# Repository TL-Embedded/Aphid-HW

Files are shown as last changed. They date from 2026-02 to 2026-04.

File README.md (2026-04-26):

# Aphid-HW

The Aphid Debugger provides a SWD and UART link via FT2232.

The 10 pin connector is compatible with the [10 pin standard here](https://github.com/TL-Embedded/SWD-UART-CTX-10).

The DTR signal can be used to apply +5V to the target `VCC AUX`.
The RTS signal can be used to ground the target `Detect`.

| Pin | Signal | IO | Description |
| --- | --- | --- | --- |
| 1 | VCC Target | Power input | Reference voltage for logic IO |
| 2 | SWDIO | Logic bidirectional | SWD Data line |
| 3 | GND | | Common ground |
| 4 | SWCLK | Logic output | SWD Clock line |
| 5 | VCC Aux | Power output | 5V power output |
| 6 | N/C | | Not connected |
| 7 | TX | Logic output | UART Transmit |
| 8 | Detect | Open drain | Debugger presence indicator |
| 9 | RX | Logic input | UART Receive |
| 10  | Reset | Open drain | Reset signal |

> [!CAUTION]
> DTR is usually automatically enabled by most terminal programs, which will enable `VCC Aux`. Ensure your target supports +5V on this pin, or remove R11 to disable this output.

# SWD interface

The SWD Debug interface is available on port 0 of the FT2232 as a D2XX device. It provides control of the SWD interface & Reset.

This is intended to be compatible with [OpenOCD](https://openocd.org/) using the [aphid-v1.cfg](./config/aphid-v1.cfg) config.

This may be copied into your openocd scripts folder, ie:
```
cp ./config/aphid-v1.cfg /usr/share/openocd/scripts/interface/ftdi/
```

The following example will validate the SWD interface is working (make sure to use the correct target).
```
openocd -f config/aphid-v1.cfg -f target/stm32g0x.cfg \
    -c "init" \
    -c "reset halt" \
    -c "mdw 0x08000000 4" \
    -c "resume" \
    -c "shutdown" \
```

# UART interface

The UART interface is available on port 1 of the FT2232 as a VCOM device.

The RTS and DTR signals are used for additional control:
 * RTS active enables the Detect signal
 * DTR active enables the VCC Aux output

# FTDI Programming

The FT2232 is programmed using [FTDI PROG](https://ftdichip.com/utilities/) via USB. The programming template is provided [here](./config/aphid.ftdiconf.xml).

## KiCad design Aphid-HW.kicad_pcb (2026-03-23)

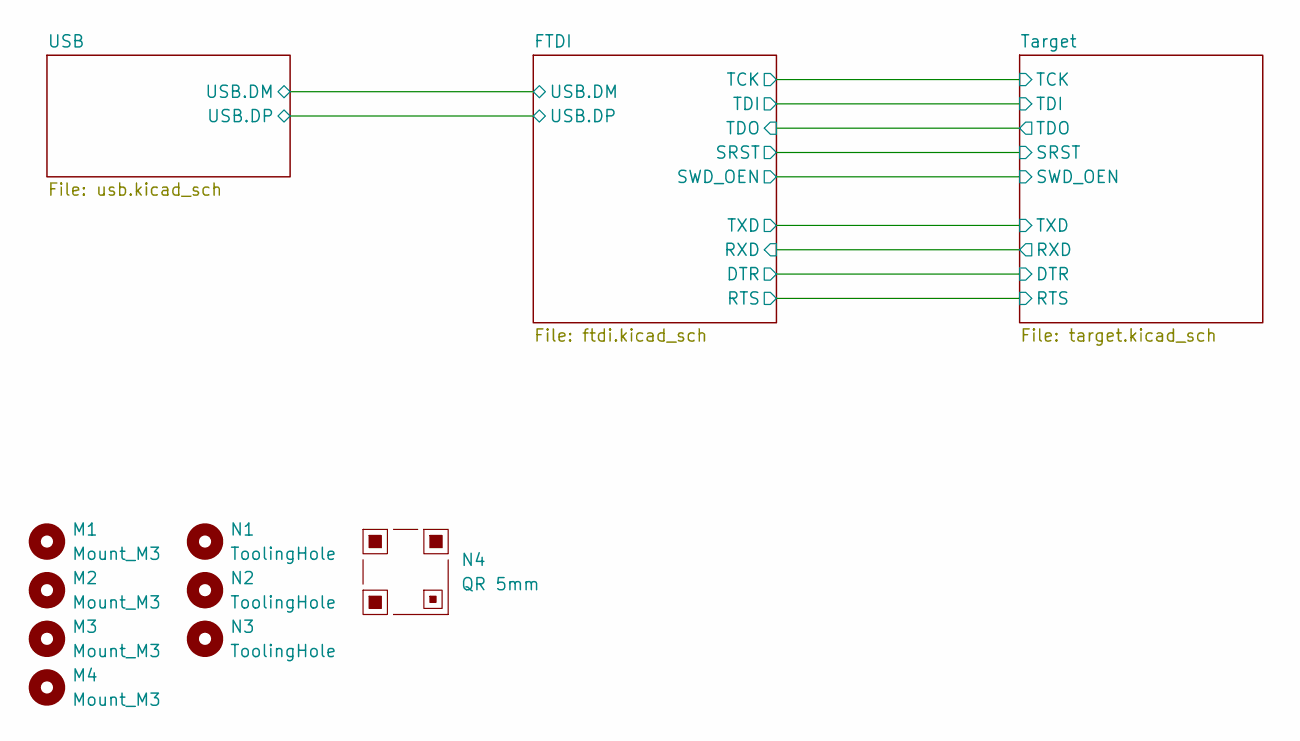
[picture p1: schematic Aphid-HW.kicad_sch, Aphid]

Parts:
M1, M2, M3, M4: Mount_M3
N1, N2, N3: ToolingHole; ToolingHole_1mm
N4: QR 5mm; QR_5mm_JLC

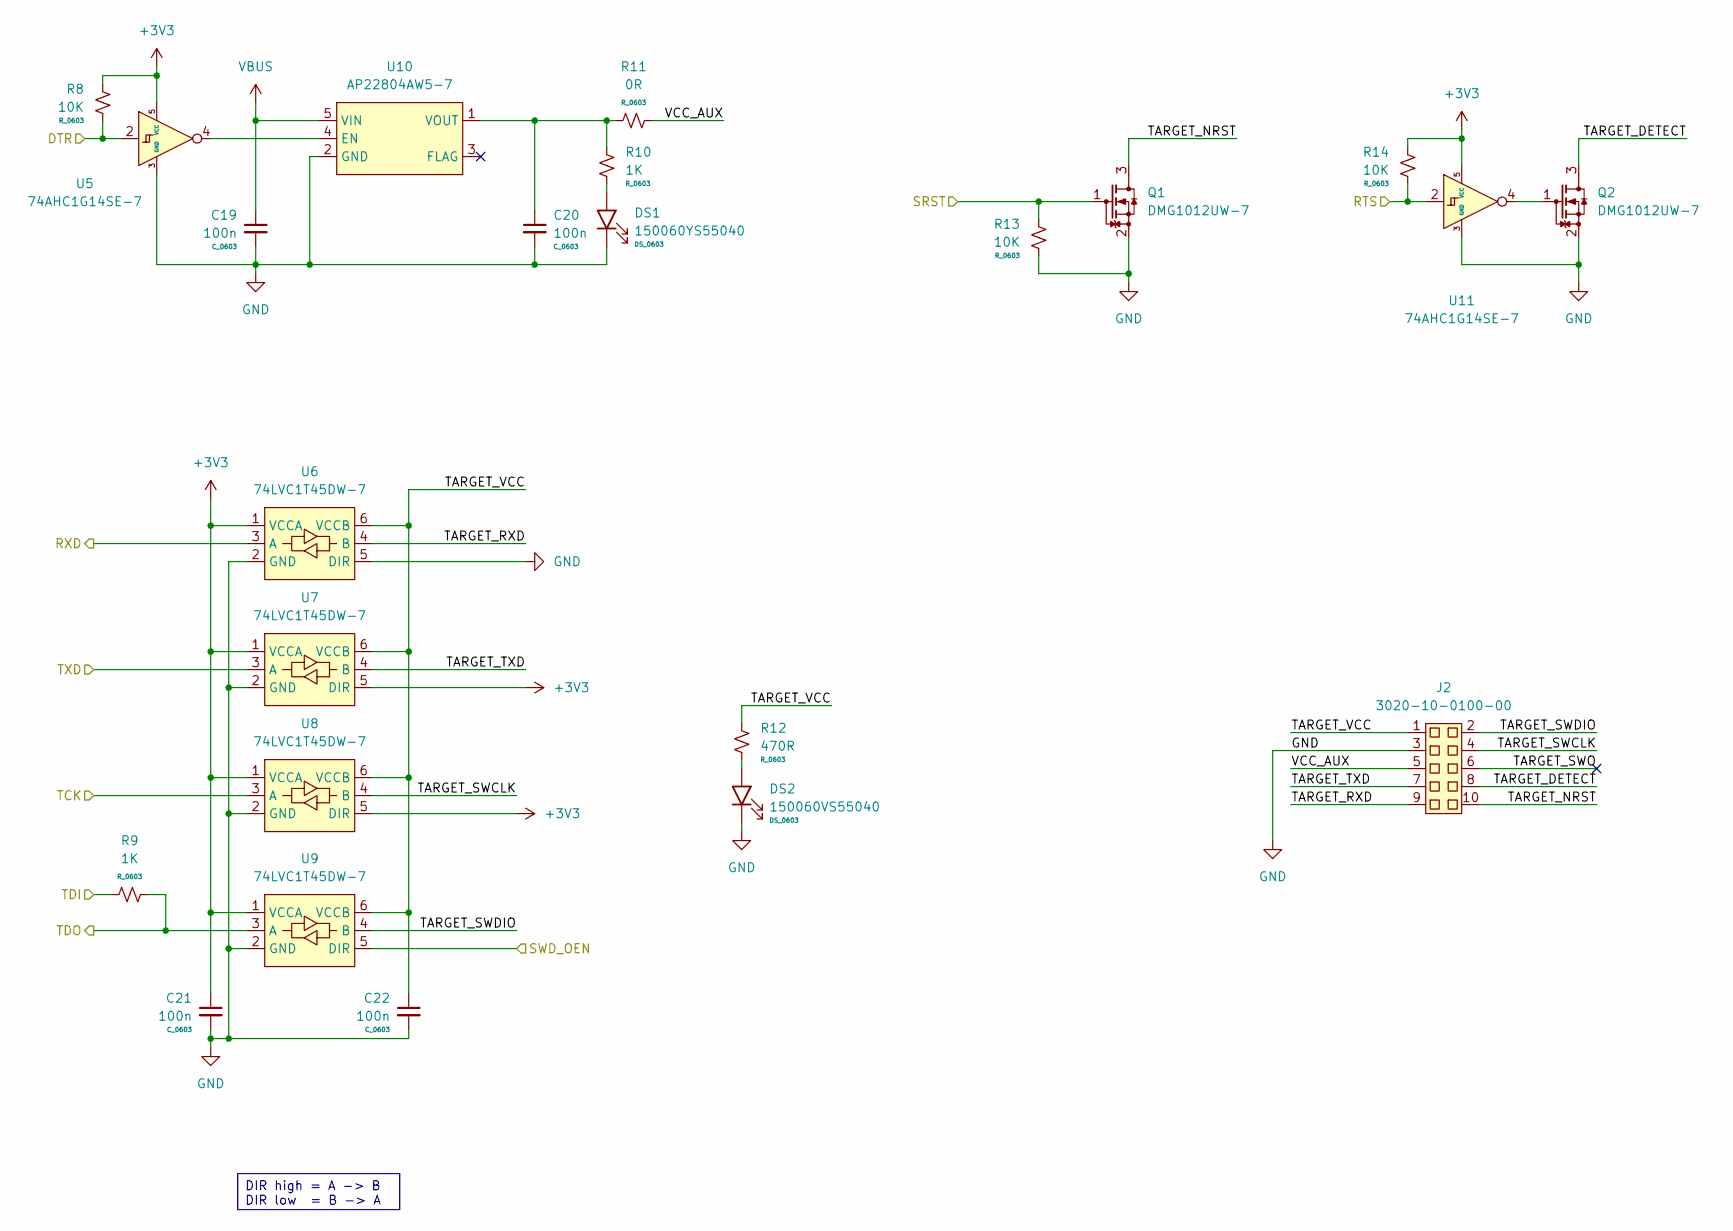
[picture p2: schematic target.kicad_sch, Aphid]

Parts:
C19, C20, C21, C22: 100n; C_0603
DS1: 150060YS55040; DS_0603
DS2: 150060VS55040; DS_0603
J2: 3020-10-0100-00; IDC-Header-02x10-2.54mm-Vert
Q1, Q2: DMG1012UW-7; SC70-3
R8, R13, R14: 10K; R_0603
R9, R10: 1K; R_0603
R11: 0R; R_0603
R12: 470R; R_0603
U5, U11: 74AHC1G14SE-7; SC70-5
U6, U7, U8, U9: 74LVC1T45DW-7; SC70-6
U10: AP22804AW5-7; SOT23_5

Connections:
+3V3: C21.1, R8.1, R14.1, U5.5 (VCC), U6.1 (VCCA), U7.1 (VCCA), U7.5 (DIR), U8.1 (VCCA), U8.5 (DIR), U9.1 (VCCA), U11.5 (VCC); also elsewhere on the board
/FTDI/DTR: R8.2, U5.2; also elsewhere on the board
/FTDI/RTS: R14.2, U11.2; also elsewhere on the board
/FTDI/RXD: U6.3 (A); also elsewhere on the board
/FTDI/SRST: Q1.1 (G), R13.1; also elsewhere on the board
/FTDI/SWD_OEN: U9.5 (DIR); also elsewhere on the board
/FTDI/TCK: U8.3 (A); also elsewhere on the board
/FTDI/TDI: R9.1; also elsewhere on the board
/FTDI/TDO: R9.2, U9.3 (A); also elsewhere on the board
/FTDI/TXD: U7.3 (A); also elsewhere on the board
/Target/TARGET_DETECT: J2.8, Q2.3 (D)
/Target/TARGET_NRST: J2.10, Q1.3 (D)
/Target/TARGET_RXD: J2.9, U6.4 (B)
/Target/TARGET_SWCLK: J2.4, U8.4 (B)
/Target/TARGET_SWDIO: J2.2, U9.4 (B)
/Target/TARGET_SWO: J2.6
/Target/TARGET_TXD: J2.7, U7.4 (B)
/Target/TARGET_VCC: C22.1, J2.1, R12.1, U6.6 (VCCB), U7.6 (VCCB), U8.6 (VCCB), U9.6 (VCCB)
/Target/VCC_AUX: J2.5, R11.2
GND: C19.2, C20.2, C21.2, C22.2, DS1.1 (K), DS2.1 (K), J2.3, Q1.2 (S), Q2.2 (S), R13.2, U5.3 (GND), U6.2 (GND), U6.5 (DIR), U7.2 (GND), U8.2 (GND), U9.2 (GND), U10.2 (GND), U11.3 (GND); also elsewhere on the board
unnamed: DS1.2 (A), R10.2
unnamed: DS2.2 (A), R12.2
unnamed: Q2.1 (G), U11.4
unnamed: U5.4, U10.4 (EN)
unnamed: C20.1, R10.1, R11.1, U10.1 (VOUT)
VBUS: C19.1, U10.5 (VIN); also elsewhere on the board

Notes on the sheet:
DIR high = A -> B DIR low = B -> A

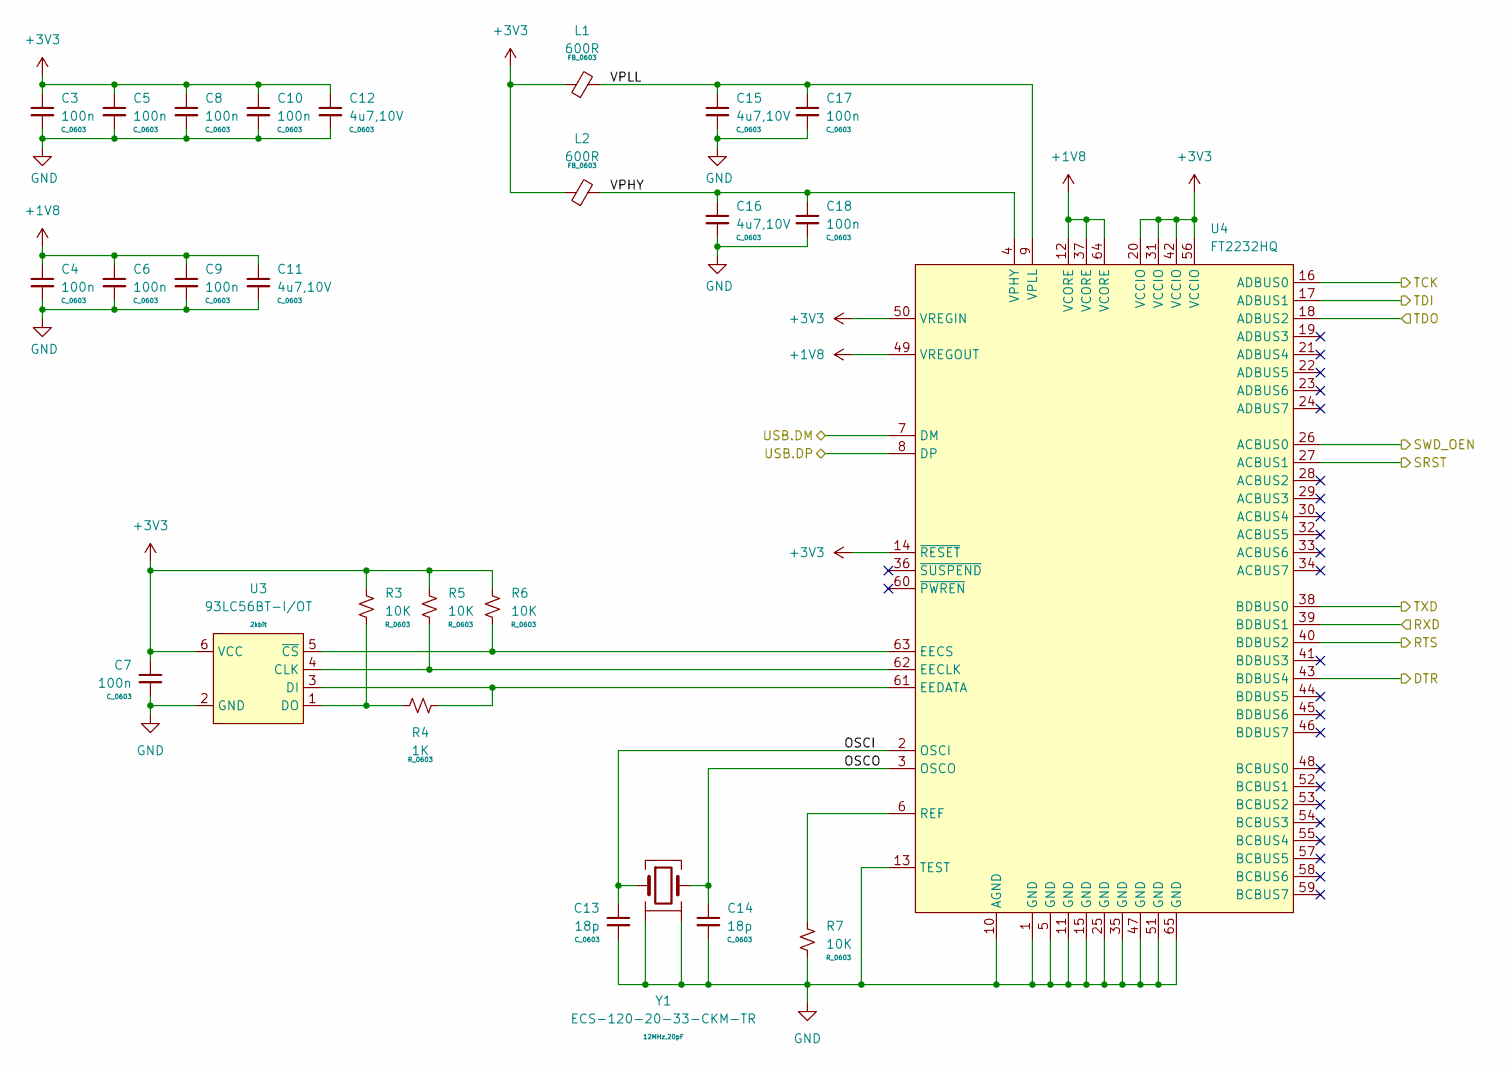
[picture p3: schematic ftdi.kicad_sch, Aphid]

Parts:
C3, C4, C5, C6, C7, C8, C9, C10, C17, C18: 100n; C_0603
C11, C12, C15, C16: 4u7,10V; C_0603
C13, C14: 18p; C_0603
L1, L2: 600R; FB_0603
R3, R5, R6, R7: 10K; R_0603
R4: 1K; R_0603
U3: 93LC56BT-I/OT; SOT23_6
U4: FT2232HQ; QFN64_05_9x9_EP_FTDI
Y1: ECS-120-20-33-CKM-TR; Crystal_SMD4_3.2x2.5

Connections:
+1V8: C4.1, C6.1, C9.1, C11.1, U4.12 (VCORE), U4.37 (VCORE), U4.49 (VREGOUT), U4.64 (VCORE)
+3V3: C3.1, C5.1, C7.1, C8.1, C10.1, C12.1, L1.1, L2.1, R3.1, R5.1, R6.1, U3.6 (VCC), U4.14 (~RESET), U4.20 (VCCIO), U4.31 (VCCIO), U4.42 (VCCIO), U4.50 (VREGIN), U4.56 (VCCIO); also elsewhere on the board
/FTDI/DTR: U4.43 (BDBUS4); also elsewhere on the board
/FTDI/OSCI: C13.1, U4.2 (OSCI), Y1.1
/FTDI/OSCO: C14.1, U4.3 (OSCO), Y1.3
/FTDI/RTS: U4.40 (BDBUS2); also elsewhere on the board
/FTDI/RXD: U4.39 (BDBUS1); also elsewhere on the board
/FTDI/SRST: U4.27 (ACBUS1); also elsewhere on the board
/FTDI/SWD_OEN: U4.26 (ACBUS0); also elsewhere on the board
/FTDI/TCK: U4.16 (ADBUS0); also elsewhere on the board
/FTDI/TDI: U4.17 (ADBUS1); also elsewhere on the board
/FTDI/TDO: U4.18 (ADBUS2); also elsewhere on the board
/FTDI/TXD: U4.38 (BDBUS0); also elsewhere on the board
/FTDI/USB.DM: U4.7 (DM); also elsewhere on the board
/FTDI/USB.DP: U4.8 (DP); also elsewhere on the board
/FTDI/VPHY: C16.1, C18.1, L2.2, U4.4 (VPHY)
/FTDI/VPLL: C15.1, C17.1, L1.2, U4.9 (VPLL)
GND: C3.2, C4.2, C5.2, C6.2, C7.2, C8.2, C9.2, C10.2, C11.2, C12.2, C13.2, C14.2, C15.2, C16.2, C17.2, C18.2, R7.2, U3.2 (GND), U4.1 (GND), U4.5 (GND), U4.10 (AGND), U4.11 (GND), U4.13 (TEST), U4.15 (GND), U4.25 (GND), U4.35 (GND), U4.47 (GND), U4.51 (GND), U4.65 (GND), Y1.2, Y1.4; also elsewhere on the board
unnamed: R5.2, U3.4 (CLK), U4.62 (EECLK)
unnamed: R4.1, U3.3 (DI), U4.61 (EEDATA)
unnamed: R3.2, R4.2, U3.1 (DO)
unnamed: R6.2, U3.5 (~CS), U4.63 (EECS)
unnamed: R7.1, U4.6 (REF)

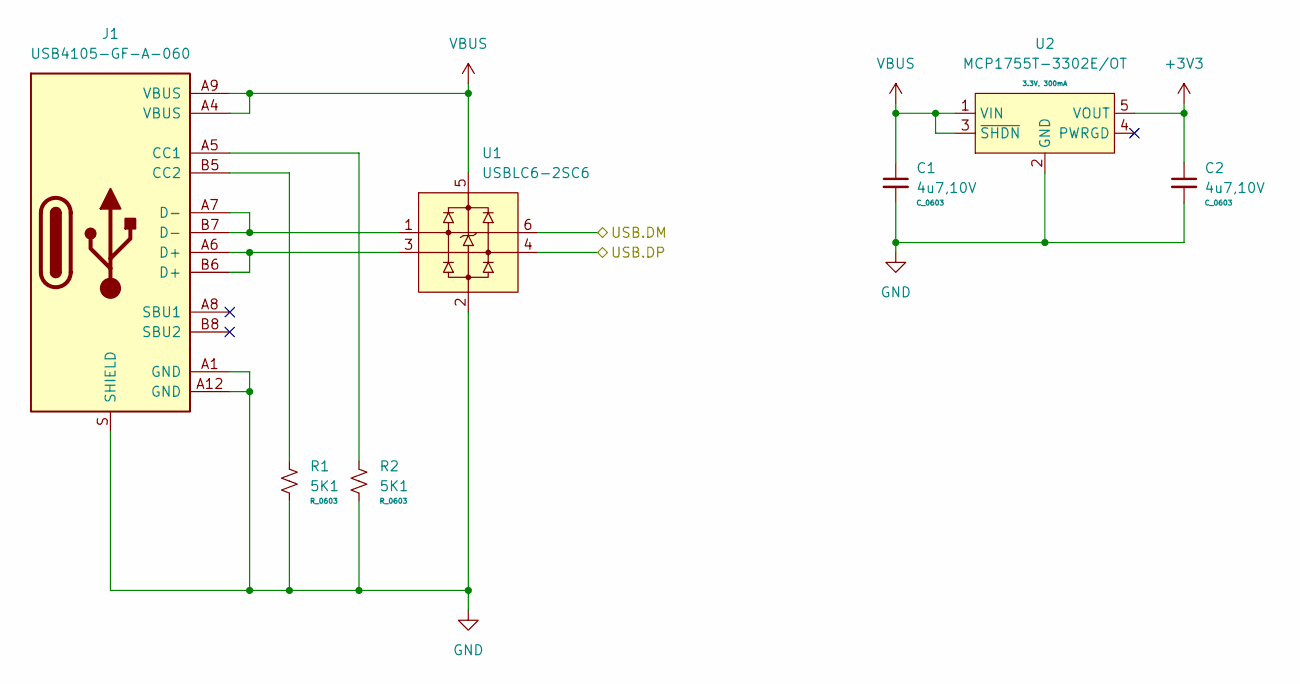
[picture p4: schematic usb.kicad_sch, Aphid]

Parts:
C1, C2: 4u7,10V; C_0603
J1: USB4105-GF-A-060; USB_C_USB4105-GF-A-060
R1, R2: 5K1; R_0603
U1: USBLC6-2SC6; SOT23_6
U2: MCP1755T-3302E/OT; SOT23_5

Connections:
+3V3: C2.1, U2.5 (VOUT); also elsewhere on the board
/FTDI/USB.DM: U1.6; also elsewhere on the board
/FTDI/USB.DP: U1.4; also elsewhere on the board
GND: C1.2, C2.2, J1.A1 (GND), J1.A12 (GND), J1.S (SHIELD), R1.2, R2.2, U1.2, U2.2 (GND); also elsewhere on the board
unnamed: J1.A5 (CC1), R2.1
unnamed: J1.B5 (CC2), R1.1
unnamed: J1.A6 (D+), J1.B6 (D+), U1.3
unnamed: J1.A7 (D-), J1.B7 (D-), U1.1
VBUS: C1.1, J1.A4 (VBUS), J1.A9 (VBUS), U1.5, U2.1 (VIN), U2.3 (~SHDN); also elsewhere on the board

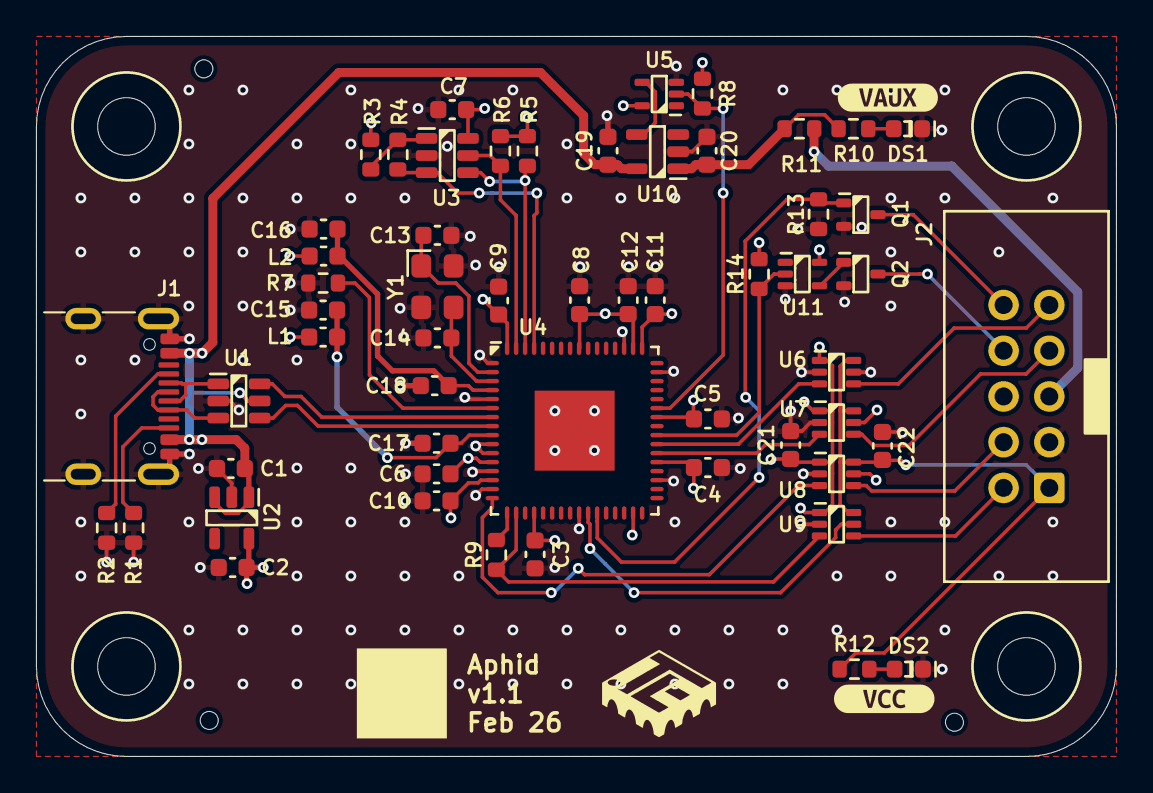
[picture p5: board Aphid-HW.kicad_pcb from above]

Board: 4 copper layers, 60.0 x 40.0 mm, 66 parts (0 on the bottom side), 41 nets.

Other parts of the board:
kibuzzard-69A2682E: G***; kibuzzard-69A2682E
kibuzzard-69A26839: G***; kibuzzard-69A26839

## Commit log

2026-03-21 Rework logic gates
    Rename to aphid
    [Aphid-HW.kicad_pcb, Aphid-HW.kicad_sch, ftdi.kicad_sch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]
2026-03-23 Update PCB layout
    [Aphid-HW.kicad_pcb, Aphid-HW.kicad_sch, ftdi.kicad_sch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]
2026-03-23 Update output colours.
    [Aphid-HW.kicad_pcb]
2026-04-26 Add openOCD conf
    Update readme
    [aphid-v1.cfg]
